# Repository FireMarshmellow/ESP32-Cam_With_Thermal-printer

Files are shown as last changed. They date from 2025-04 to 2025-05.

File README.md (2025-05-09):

# Capture\_Dither\_Save\_Print\_V3
## Project video
Video Title (https://www.youtube.com/watch?v=8lnDPz4QZjQ)

## Overview

`Capture_Dither_Save_Print_V3` is an Arduino sketch designed for the ESP32-CAM to:

* Capture an image from the camera module
* Convert the image to a black-and-white dithered format suitable for thermal printing
* Save the processed image (optional on SD card)
* Send the dithered image to a thermal printer for immediate physical output

This repository contains all the code and instructions needed to get your ESP32-CAM and DFRobot thermal printer up and running.

## Hardware Requirements

* **ESP32-CAM module** (with OPI PSRAM) from DFRobot

  * Product link: [https://www.dfrobot.com/product-2899.html?marketing=67c824f1362b5](https://www.dfrobot.com/product-2899.html?marketing=67c824f1362b5)
* **DFRobot Thermal Printer** (V2/TTL) from DFRobot

  * Product link: [https://www.dfrobot.com/product-1799.html](https://www.dfrobot.com/product-1799.html)

## Installation

1. **Clone this repository**

   ```bash
   git clone https://github.com/yourusername/your-repo.git
   cd your-repo
   ```
2. **Open the sketch**

   * Launch Arduino IDE and open `Capture_Dither_Save_Print_V3.ino` from this folder.
3. **Select board and port**

   * **Board**: Select **AI Thinker ESP32-CAM** (or the matching ESP32-CAM variant).
   * **PSRAM**: **Enabled** (required for image buffering)
   * **Upload Speed**: 115200
   * **Port**: Select the COM port for your USB-to-Serial adapter

## Usage

1. **Compile & Upload**

   * Click the **Upload** button in Arduino IDE.
2. **Monitor Serial Output**

   * Open the Serial Monitor at **115200 baud** to view status messages.
3. **Capture & Print**

   * After boot, the ESP32-CAM will automatically capture an image, apply Floyd–Steinberg dithering, save it to the SD card (if available), and send it to the thermal printer.
   * Wait a few seconds for the printer to finish outputting the image.

## Troubleshooting

* **Blank Prints**: Ensure PSRAM is enabled and sufficient power is supplied to the printer.
* **Compilation Errors**: Verify you have the correct ESP32 board package and PSRAM setting.
* **SD Card Issues**: Make sure card is formatted as FAT32 and wiring matches your pin definitions.

## Acknowledgments

* Based on example code from the [`esp32-camera`](https://github.com/espressif/esp32-camera) library
* DFRobot for hardware modules and documentation

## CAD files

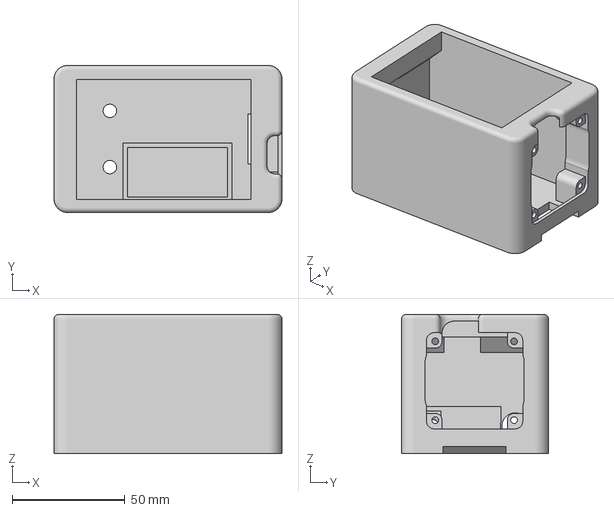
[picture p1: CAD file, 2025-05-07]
Camera Body.3mf
101.3 x 65.3 x 61.9 mm

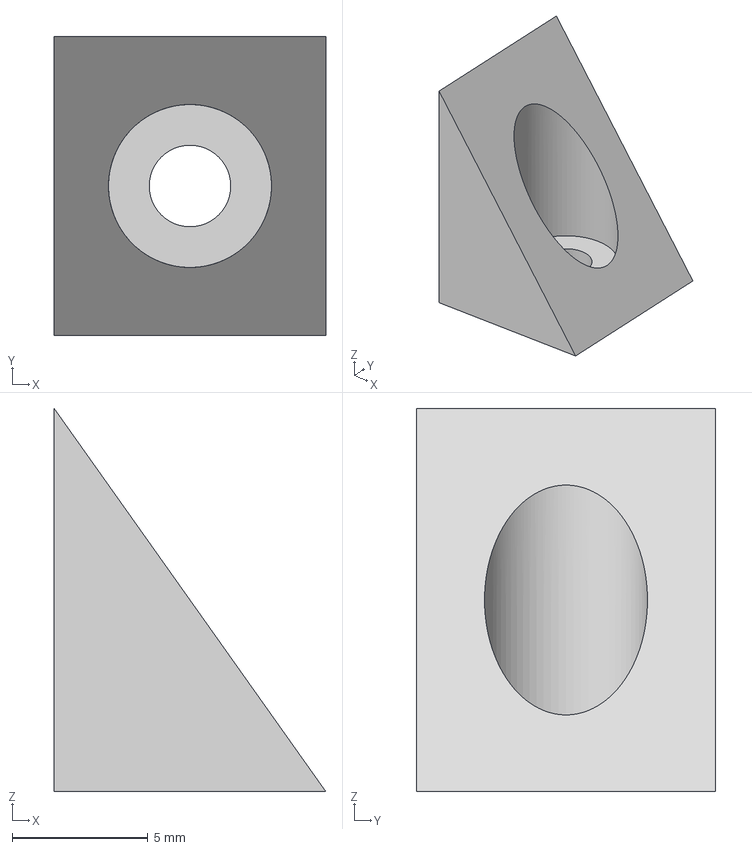
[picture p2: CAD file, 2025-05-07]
Button retainer.3mf
10.0 x 11.0 x 14.1 mm

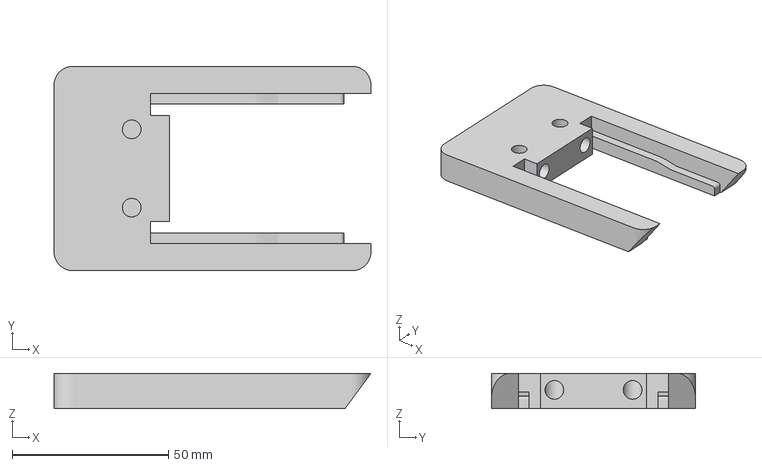
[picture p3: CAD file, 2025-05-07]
Battery holder.3mf
101.3 x 65.3 x 11.3 mm

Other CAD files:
Diy Instant Camera.f3d

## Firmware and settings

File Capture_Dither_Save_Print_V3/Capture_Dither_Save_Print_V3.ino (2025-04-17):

// ONLY Works with the below ESP32 and printer:
// https://wiki.dfrobot.com/SKU_DFR0503_EN_Embedded_Thermal_Printer_V2.0
// https://www.dfrobot.com/product-2899.html?marketing=67c824f1362b5

#include "Adafruit_Thermal.h"
#include "esp_camera.h"
#include "FS.h"
#include "SD.h"
#include "SPI.h"

// ------------------ Printer Setup ------------------
#define TX_PIN 43  // ESP TX → Printer RX 
#define RX_PIN 44  // ESP RX → Printer TX 

HardwareSerial mySerial(1);  // Use HardwareSerial instance 1
Adafruit_Thermal printer(&mySerial);

// ------------------ Camera & SD Setup ------------------
// CAMERA PINS (DFRobot ESP32-S3 AI Camera OV3660)
#define PWDN_GPIO_NUM     -1
#define RESET_GPIO_NUM    -1
#define XCLK_GPIO_NUM      5
#define SIOD_GPIO_NUM      8
#define SIOC_GPIO_NUM      9
#define Y9_GPIO_NUM        4
#define Y8_GPIO_NUM        6
#define Y7_GPIO_NUM        7
#define Y6_GPIO_NUM       14
#define Y5_GPIO_NUM       17
#define Y4_GPIO_NUM       21
#define Y3_GPIO_NUM       18
#define Y2_GPIO_NUM       16
#define VSYNC_GPIO_NUM     1
#define HREF_GPIO_NUM      2
#define PCLK_GPIO_NUM     15

// SD Card Pins
#define SD_CS     10
#define SD_MOSI   11
#define SD_MISO   13
#define SD_CLK    12

#define BOOT_BUTTON_PIN  0  // Active LOW

#define IND_LED_PIN 3
#define IR_LED_PIN 47

#define CONTRAST_FACTOR 1.2f   // increase contrast ( >1.0 increases contrast)
#define SHARPEN_AMOUNT 0.2f    // horizontal sharpening factor

int fileCounter = 0;

// ------------------ Function Prototypes ------------------
void waitForButtonPress();
String saveBMPtoSD();
bool printBMP(const String &bmpFilename);
void printBitmapRaw(const uint8_t *bitmap, uint16_t width, uint16_t height);
void flipBitmapVertically(uint8_t *bitmap, uint16_t height, uint16_t rowBytes);
int getNextFileCounter();

// Add an enum to distinguish actions:
enum ButtonAction {
    CAPTURE_PHOTO,
    PRINT_LAST
};

// New function to wait for a button action:
// If the button is held down for >= 2 seconds, return PRINT_LAST.
ButtonAction waitForButtonAction() {
  Serial.println("Waiting for button press (hold >2 sec to print last photo)...");
  // Wait until user presses the button
  while (digitalRead(BOOT_BUTTON_PIN) == HIGH) {
    delay(10);
  }
  // Measure the time the button is held down
  unsigned long start = millis();
  while (digitalRead(BOOT_BUTTON_PIN) == LOW) {
    delay(10);
  }
  unsigned long duration = millis() - start;
  if (duration >= 2000) {
    Serial.println("Long press detected - printing last photo.");
    return PRINT_LAST;
  }
  Serial.println("Short press detected - capturing new photo.");
  return CAPTURE_PHOTO;
}

// ------------------ Flip Bitmap Vertically ------------------
void flipBitmapVertically(uint8_t *bitmap, uint16_t height, uint16_t rowBytes) {
  uint8_t *temp = (uint8_t *) malloc(rowBytes);
  if (!temp) {
    Serial.println("Failed to allocate temp buffer for flipping");
    return;
  }
  for (uint16_t i = 0; i < height / 2; i++) {
    memcpy(temp, bitmap + i * rowBytes, rowBytes);
    memcpy(bitmap + i * rowBytes, bitmap + (height - 1 - i) * rowBytes, rowBytes);
    memcpy(bitmap + (height - 1 - i) * rowBytes, temp, rowBytes);
  }
  free(temp);
}

// ------------------ Setup ------------------
void setup() {
  Serial.begin(115200);
  delay(1000);

  mySerial.begin(115200, SERIAL_8N1, RX_PIN, TX_PIN);
  printer.begin();

  pinMode(BOOT_BUTTON_PIN, INPUT_PULLUP);
  pinMode(IND_LED_PIN, OUTPUT);
  pinMode(IR_LED_PIN, OUTPUT);
  digitalWrite(IND_LED_PIN, LOW);
  digitalWrite(IR_LED_PIN, LOW);

  camera_config_t config;
  config.ledc_channel = LEDC_CHANNEL_0;
  config.ledc_timer = LEDC_TIMER_0;
  config.pin_d0 = Y2_GPIO_NUM;
  config.pin_d1 = Y3_GPIO_NUM;
  config.pin_d2 = Y4_GPIO_NUM;
  config.pin_d3 = Y5_GPIO_NUM;
  config.pin_d4 = Y6_GPIO_NUM;
  config.pin_d5 = Y7_GPIO_NUM;
  config.pin_d6 = Y8_GPIO_NUM;
  config.pin_d7 = Y9_GPIO_NUM;
  config.pin_xclk = XCLK_GPIO_NUM;
  config.pin_pclk = PCLK_GPIO_NUM;
  config.pin_vsync = VSYNC_GPIO_NUM;
  config.pin_href = HREF_GPIO_NUM;
  config.pin_sccb_sda = SIOD_GPIO_NUM;
  config.pin_sccb_scl = SIOC_GPIO_NUM;
  config.pin_pwdn = PWDN_GPIO_NUM;
  config.pin_reset = RESET_GPIO_NUM;
  config.xclk_freq_hz = 20000000;
  config.pixel_format = PIXFORMAT_RGB565;
  config.frame_size = FRAMESIZE_CIF;
  config.fb_count = 1;
  config.fb_location = CAMERA_FB_IN_PSRAM;
  config.grab_mode = CAMERA_GRAB_LATEST;

  if (psramFound()) {
    Serial.println("PSRAM detected. Using 2 frame buffers.");
    config.fb_count = 2;
  } else {
    Serial.println("No PSRAM detected.");
  }

  esp_err_t err = esp_camera_init(&config);
  if (err != ESP_OK) {
    Serial.printf("Camera init failed: 0x%x\n", err);
    return;
  }

  SPI.begin(SD_CLK, SD_MISO, SD_MOSI, SD_CS);
  if (!SD.begin(SD_CS)) {
    Serial.println("SD card init failed!");
    return;
  }

  fileCounter = getNextFileCounter();
  Serial.printf("Next available file number: %d\n", fileCounter);
  Serial.println("Setup complete.");
}

// ------------------ Main Loop ------------------
void loop() {
  ButtonAction action = waitForButtonAction();

  if (action == PRINT_LAST) {
    if (fileCounter > 0) {
      char filename[32];
      // Last photo is fileCounter - 1
      snprintf(filename, sizeof(filename), "/photo%03d.bmp", fileCounter - 1);
      if (printBMP(String(filename))) {
        Serial.println("Printing last photo complete.");
      } else {
        Serial.println("Failed to print last photo.");
      }
    } else {
      Serial.println("No photo available to print.");
    }
  } else { // CAPTURE_PHOTO
    // Turn on IR LED and flash the indicator LED before capturing the photo
    digitalWrite(IR_LED_PIN, HIGH);     // Activate IR LEDs
    digitalWrite(IND_LED_PIN, HIGH);      // Turn on indicator LED
    delay(100);                         // Flash duration
    digitalWrite(IND_LED_PIN, LOW);       // Turn off indicator LED

    String bmpPath = saveBMPtoSD();

    digitalWrite(IR_LED_PIN, LOW);        // Turn off IR LEDs after capture

    if (bmpPath != "") {
      if (printBMP(bmpPath)) {
        Serial.println("Printing complete.");
      } else {
        Serial.println("Printing failed.");
      }
      fileCounter++;
    }
  }
  delay(1000);
}

// ------------------ Save BMP to SD ------------------
String saveBMPtoSD() {
  camera_fb_t *fb = esp_camera_fb_get();
  if (!fb) {
    Serial.println("Camera capture failed");
    return "";
  }

  uint8_t* bmp_buf = NULL;
  size_t bmp_len = 0;
  bool success = frame2bmp(fb, &bmp_buf, &bmp_len);
  esp_camera_fb_return(fb);

  if (!success || !bmp_buf) {
    Serial.println("BMP conversion failed");
    return "";
  }

  char filename[32];
  snprintf(filename, sizeof(filename), "/photo%03d.bmp", fileCounter);
  File file = SD.open(filename, FILE_WRITE);
  if (!file) {
    Serial.println("Failed to open BMP file");
    free(bmp_buf);
    return "";
  }

  file.write(bmp_buf, bmp_len);
  file.close();
  free(bmp_buf);

  Serial.printf("Saved %s\n", filename);
  return String(filename);
}

// ------------------ Get Next Available File Counter ------------------
int getNextFileCounter() {
  int counter = 0;
  while (true) {
    char filename[32];
    snprintf(filename, sizeof(filename), "/photo%03d.bmp", counter);
    if (!SD.exists(filename)) {
      return counter;
    }
    counter++;
    if (counter > 999) break;
  }
  return counter;
}

// ------------------ Print BMP ------------------
bool printBMP(const String &bmpFilename) {
  File bmp = SD.open(bmpFilename);
  if (!bmp) {
    Serial.println("Failed to open BMP file for reading");
    return false;
  }

  uint8_t header[54];
  if (bmp.read(header, 54) != 54) {
    Serial.println("Failed to read BMP header");
    bmp.close();
    return false;
  }

  int32_t width = *(int32_t*)&header[18];
  int32_t height_raw = *(int32_t*)&header[22];
  bool isTopDown = (height_raw < 0);
  int32_t height = abs(height_raw);
  uint16_t bpp = *(uint16_t*)&header[28];
  uint32_t offset = *(uint32_t*)&header[10];

  if (bpp != 24) {
    Serial.println("Only 24-bit BMP supported");
    bmp.close();
    return false;
  }

  int rowSize = (width * 3 + 3) & ~3;
  bmp.seek(offset);

  float* rowA = (float*) ps_malloc(width * sizeof(float));
  float* rowB = (float*) ps_malloc(width * sizeof(float));
  if (!rowA || !rowB) {
    Serial.println("Failed to allocate dither rows");
    bmp.close();
    if (rowA) free(rowA);
    if (rowB) free(rowB);
    return false;
  }

  // Preload first row:
  int preloadY = isTopDown ? 0 : height - 1;
  bmp.seek(offset + rowSize * preloadY);
  for (int x = 0; x < width; x++) {
    uint8_t b = bmp.read();
    uint8_t g = bmp.read();
    uint8_t r = bmp.read();
    float gray = 0.299f * r + 0.587f * g + 0.114f * b;
    gray = 128 + CONTRAST_FACTOR * (gray - 128);
    if(gray < 0) gray = 0;
    if(gray > 255) gray = 255;
    rowB[x] = gray;
  }

  uint16_t widthBytes = (width + 7) / 8;
  uint8_t* ditheredBitmap = (uint8_t*) malloc(height * widthBytes);
  if (!ditheredBitmap) {
    Serial.println("Failed to allocate dithered bitmap buffer");
    bmp.close();
    free(rowA);
    free(rowB);
    return false;
  }
  size_t byteIndex = 0;

  for (int i = 0; i < height; i++) {
    int y = isTopDown ? i : (height - 1 - i);
    memcpy(rowA, rowB, width * sizeof(float));

    // Apply horizontal sharpening on rowA:
    for (int x = 1; x < width - 1; x++) {
      float sharpen = rowA[x] * (1 + SHARPEN_AMOUNT) - (rowA[x - 1] + rowA[x + 1]) * (SHARPEN_AMOUNT / 2);
      if(sharpen < 0) sharpen = 0;
      if(sharpen > 255) sharpen = 255;
      rowA[x] = sharpen;
    }

    if (i < height - 1) {
      int nextY = isTopDown ? (i + 1) : (height - 2 - i);
      bmp.seek(offset + rowSize * nextY);
      for (int x = 0; x < width; x++) {
        uint8_t b = bmp.read();
        uint8_t g = bmp.read();
        uint8_t r = bmp.read();
        float gray = 0.299f * r + 0.587f * g + 0.114f * b;
        gray = 128 + CONTRAST_FACTOR * (gray - 128);
        if(gray < 0) gray = 0;
        if(gray > 255) gray = 255;
        rowB[x] = gray;
      }
    } else {
      memset(rowB, 255, width * sizeof(float));
    }

    uint8_t outByte = 0;
    int bit = 7;

    for (int x = 0; x < width; x++) {
      float oldPixel = rowA[x];
      float newPixel = oldPixel < 128 ? 0 : 255;
      float error = oldPixel - newPixel;
      rowA[x] = newPixel;

      if (x + 1 < width) rowA[x + 1] += error * 7.0f / 16.0f;
      if (i < height - 1) {
        if (x > 0)         rowB[x - 1] += error * 3.0f / 16.0f;
                           rowB[x    ] += error * 5.0f / 16.0f;
        if (x + 1 < width) rowB[x + 1] += error * 1.0f / 16.0f;
      }

      if (newPixel < 128) outByte |= (1 << bit);
      bit--;

      if (bit < 0 || x == width - 1) {
        ditheredBitmap[byteIndex++] = outByte;
        outByte = 0;
        bit = 7;
      }
    }
  }

  String displayName = bmpFilename.substring(1, bmpFilename.length() - 4);
  //printer.println("You Met Mellow! At Mellow_Con");
  printBitmapRaw(ditheredBitmap, width, height);
  printer.println(displayName);
  printer.feed(1);

  free(ditheredBitmap);
  free(rowA);
  free(rowB);
  bmp.close();
  return true;
}

// ------------------ Print Bitmap Raw ------------------
void printBitmapRaw(const uint8_t *bitmap, uint16_t width, uint16_t height) {
  uint16_t widthBytes = (width + 7) / 8;
  uint8_t xL = widthBytes & 0xFF;
  uint8_t xH = (widthBytes >> 8) & 0xFF;
  uint8_t yL = height & 0xFF;
  uint8_t yH = (height >> 8) & 0xFF;

  mySerial.write((uint8_t)0x1D);
  mySerial.write((uint8_t)0x76);
  mySerial.write((uint8_t)0x30);
  mySerial.write((uint8_t)0x00);
  mySerial.write((uint8_t)xL);
  mySerial.write((uint8_t)xH);
  mySerial.write((uint8_t)yL);
  mySerial.write((uint8_t)yH);

  for (uint16_t i = 0; i < height * widthBytes; i++) {
    mySerial.write(pgm_read_byte(bitmap + i));
  }
}

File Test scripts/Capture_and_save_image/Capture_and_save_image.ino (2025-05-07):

#include "esp_camera.h"
#include "FS.h"
#include "SD.h"
#include "SPI.h"

// ——— SD Card Pins ———
#define SD_CS     10
#define SD_MOSI   11
#define SD_MISO   13
#define SD_CLK    12

// ——— Camera Pins (DFRobot ESP32-S3 AI Camera OV3660) ———
#define PWDN_GPIO_NUM     -1
#define RESET_GPIO_NUM    -1
#define XCLK_GPIO_NUM      5
#define SIOD_GPIO_NUM      8
#define SIOC_GPIO_NUM      9
#define Y9_GPIO_NUM        4
#define Y8_GPIO_NUM        6
#define Y7_GPIO_NUM        7
#define Y6_GPIO_NUM       14
#define Y5_GPIO_NUM       17
#define Y4_GPIO_NUM       21
#define Y3_GPIO_NUM       18
#define Y2_GPIO_NUM       16
#define VSYNC_GPIO_NUM     1
#define HREF_GPIO_NUM      2
#define PCLK_GPIO_NUM     15

// ——— Boot Button ———
#define BOOT_BUTTON_PIN    0  // ESP32 on-board BOOT button (active LOW)

int fileCounter = 0;

void setup() {
  Serial.begin(115200);
  delay(1000);

  // ——— Initialize SD card ———
  SPI.begin(SD_CLK, SD_MISO, SD_MOSI, SD_CS);
  if (!SD.begin(SD_CS)) {
    Serial.println("❌ SD card init failed!");
    while (true) delay(1000);
  }
  Serial.println("✅ SD card initialized");

  // ——— Configure camera ———
  camera_config_t config;
  // Pin assignments
  config.pin_pwdn     = PWDN_GPIO_NUM;
  config.pin_reset    = RESET_GPIO_NUM;
  config.pin_xclk     = XCLK_GPIO_NUM;
  config.pin_sccb_sda = SIOD_GPIO_NUM;
  config.pin_sccb_scl = SIOC_GPIO_NUM;
  config.pin_d7       = Y9_GPIO_NUM;
  config.pin_d6       = Y8_GPIO_NUM;
  config.pin_d5       = Y7_GPIO_NUM;
  config.pin_d4       = Y6_GPIO_NUM;
  config.pin_d3       = Y5_GPIO_NUM;
  config.pin_d2       = Y4_GPIO_NUM;
  config.pin_d1       = Y3_GPIO_NUM;
  config.pin_d0       = Y2_GPIO_NUM;
  config.pin_vsync    = VSYNC_GPIO_NUM;
  config.pin_href     = HREF_GPIO_NUM;
  config.pin_pclk     = PCLK_GPIO_NUM;

  // Camera settings
  config.xclk_freq_hz = 20000000;
  config.pixel_format = PIXFORMAT_RGB565;
  config.frame_size   = FRAMESIZE_VGA;

  // LEDC (XCLK) settings
  config.ledc_channel = LEDC_CHANNEL_0;
  config.ledc_timer   = LEDC_TIMER_0;

  // Frame buffers
  config.fb_count     = psramFound() ? 2 : 1;
  if (config.fb_count == 2) {
    Serial.println("PSRAM found: using 2 frame buffers");
  }

  esp_err_t err = esp_camera_init(&config);
  if (err != ESP_OK) {
    Serial.printf("❌ Camera init failed: 0x%x\n", err);
    while (true) delay(1000);
  }
  Serial.println("✅ Camera initialized");

  // ——— Prepare boot button ———
  pinMode(BOOT_BUTTON_PIN, INPUT_PULLUP);

  // ——— Determine next free filename ———
  while (true) {
    char path[32];
    sprintf(path, "/photo%03d.bmp", fileCounter);
    if (!SD.exists(path)) break;
    fileCounter++;
  }
  Serial.printf("Next file: photo%03d.bmp\n", fileCounter);
}

void loop() {
  // ——— Wait for BOOT button press & release ———
  Serial.println("Waiting for BOOT button press...");
  while (digitalRead(BOOT_BUTTON_PIN) == HIGH) {
    delay(10);
  }
  delay(50);  // debounce
  while (digitalRead(BOOT_BUTTON_PIN) == LOW) {
    delay(10);
  }
  delay(50);
  Serial.println("Button pressed - capturing image");

  // ——— Capture frame ———
  camera_fb_t *fb = esp_camera_fb_get();
  if (!fb) {
    Serial.println("❌ Camera capture failed");
    delay(1000);
    return;
  }

  // ——— Convert to BMP ———
  uint8_t *bmp_buf = NULL;
  size_t bmp_len = 0;
  bool ok = frame2bmp(fb, &bmp_buf, &bmp_len);
  esp_camera_fb_return(fb);

  if (!ok || !bmp_buf) {
    Serial.println("❌ BMP conversion failed");
    if (bmp_buf) free(bmp_buf);
    delay(1000);
    return;
  }

  // ——— Save BMP to SD card ———
  char filename[32];
  sprintf(filename, "/photo%03d.bmp", fileCounter);
  File file = SD.open(filename, FILE_WRITE);
  if (!file) {
    Serial.println("❌ Failed to open file");
    free(bmp_buf);
    delay(1000);
    return;
  }
  file.write(bmp_buf, bmp_len);
  file.close();
  free(bmp_buf);

  Serial.printf("💾 Saved %s (%u bytes)\n", filename, (unsigned int)bmp_len);
  fileCounter++;

  // ——— After capture, wait a moment then loop again for next shot ———
  delay(500);
}

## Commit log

2025-04-17 Add multiple versions of the Capture Dither Save Print functionality and a new example for GOOJPRT QR204 printer
    - Implemented Capture Dither Save Print V1, V2, and V3 with enhancements in image processing, including contrast adjustment and sharpening.
    - Added functionality to capture images from the DFRobot ESP32-S3 AI Camera and print them using the Adafruit Thermal printer.
    - Introduced button actions for capturing new photos and printing the last captured photo.
    - Created a new example sketch for GOOJPRT QR204 printer using SoftwareSerial for communication.
2025-05-07 Add image capture and save functionality with SD card support
    - Implemented Capture_and_save_image.ino to capture images using the ESP32 camera and save them as BMP files on an SD card.
    - Added functionality to determine the next available filename for saving images.
    - Integrated button press handling to trigger image capture.
    - Implemented BMP conversion from the camera frame buffer before saving to SD card.
    Add image capture, save, and print functionality with thermal printer support
    - Developed Capture_save_print.ino to capture images, save them as BMP files on an SD card, and print them using a thermal printer.
    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
    [Battery holder.3mf, Button retainer.3mf, Camera Body.3mf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]
2025-05-07 Add README documentation for Capture Dither Save Print V3 functionality
